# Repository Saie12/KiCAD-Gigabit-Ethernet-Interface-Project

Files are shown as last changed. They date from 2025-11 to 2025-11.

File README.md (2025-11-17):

# 🚀 High-Speed Gigabit Ethernet Interface

Welcome! This repository contains the complete hardware design files for a custom-built, 6-layer Gigabit Ethernet interface board.

The design is centered around the powerful **STM32F746NGH6** (an ARM Cortex-M7 MCU) and the **DP83867IR** Gigabit PHY. The entire layout was planned to meet strict high-speed design rules, featuring a robust multi-rail power supply and controlled impedance routing for 1Gbps performance.

## 🛠️ Key Features & Components

* **Brain (MCU):** `STM32F746NGH6` (ARM Cortex-M7)
* **Translator (PHY):** `DP83867IRPAPT` (10/100/1000 Mbps Gigabit PHY)
* **Data Interface:** `RGMII`
* **Port (Connector):** `ARJM11D7-502-AB-EW2` (A shielded Gigabit MagJack with integrated LEDs)
* **Power Supply:** 5V USB-C input, feeding a "power tree" of four independent LDOs for ultra-clean `+3.3V`, `+2.5V`, `+1.8V`, and `+1.1V` rails.
* **PCB:** Custom 6-layer, 80x50mm board with controlled impedance routing.
* **Debug:** Standard 10-pin ARM SWD (Serial Wire Debug) header.

## ✅ Hardware Project Status: Complete!

This repository covers the complete hardware design and manufacturing file generation. All phases of the hardware build are finished.

* ✅ **Phase 1: Component Selection**
    * *Selected and verified the core MCU, PHY, MagJack, and all power components for Gigabit-speed requirements.*
* ✅ **Phase 2: Schematic Design**
    * *Created the full electronic blueprint, connecting all components and defining all power and signal nets.*
* ✅ **Phase 3: Pre-Layout Checks**
    * *Ran a full Electrical Rules Check (ERC) and assigned all physical component footprints.*
* ✅ **Phase 4: PCB Layout**
    * *Designed the 6-layer stackup, floorplanned all components, poured all ground and power planes, and hand-routed all 17 critical high-speed differential and RGMII traces.*
* ✅ **Phase 5: Manufacturing File Generation**
    * *Generated the final Gerber and Drill files (`.zip`) required for fabrication.*

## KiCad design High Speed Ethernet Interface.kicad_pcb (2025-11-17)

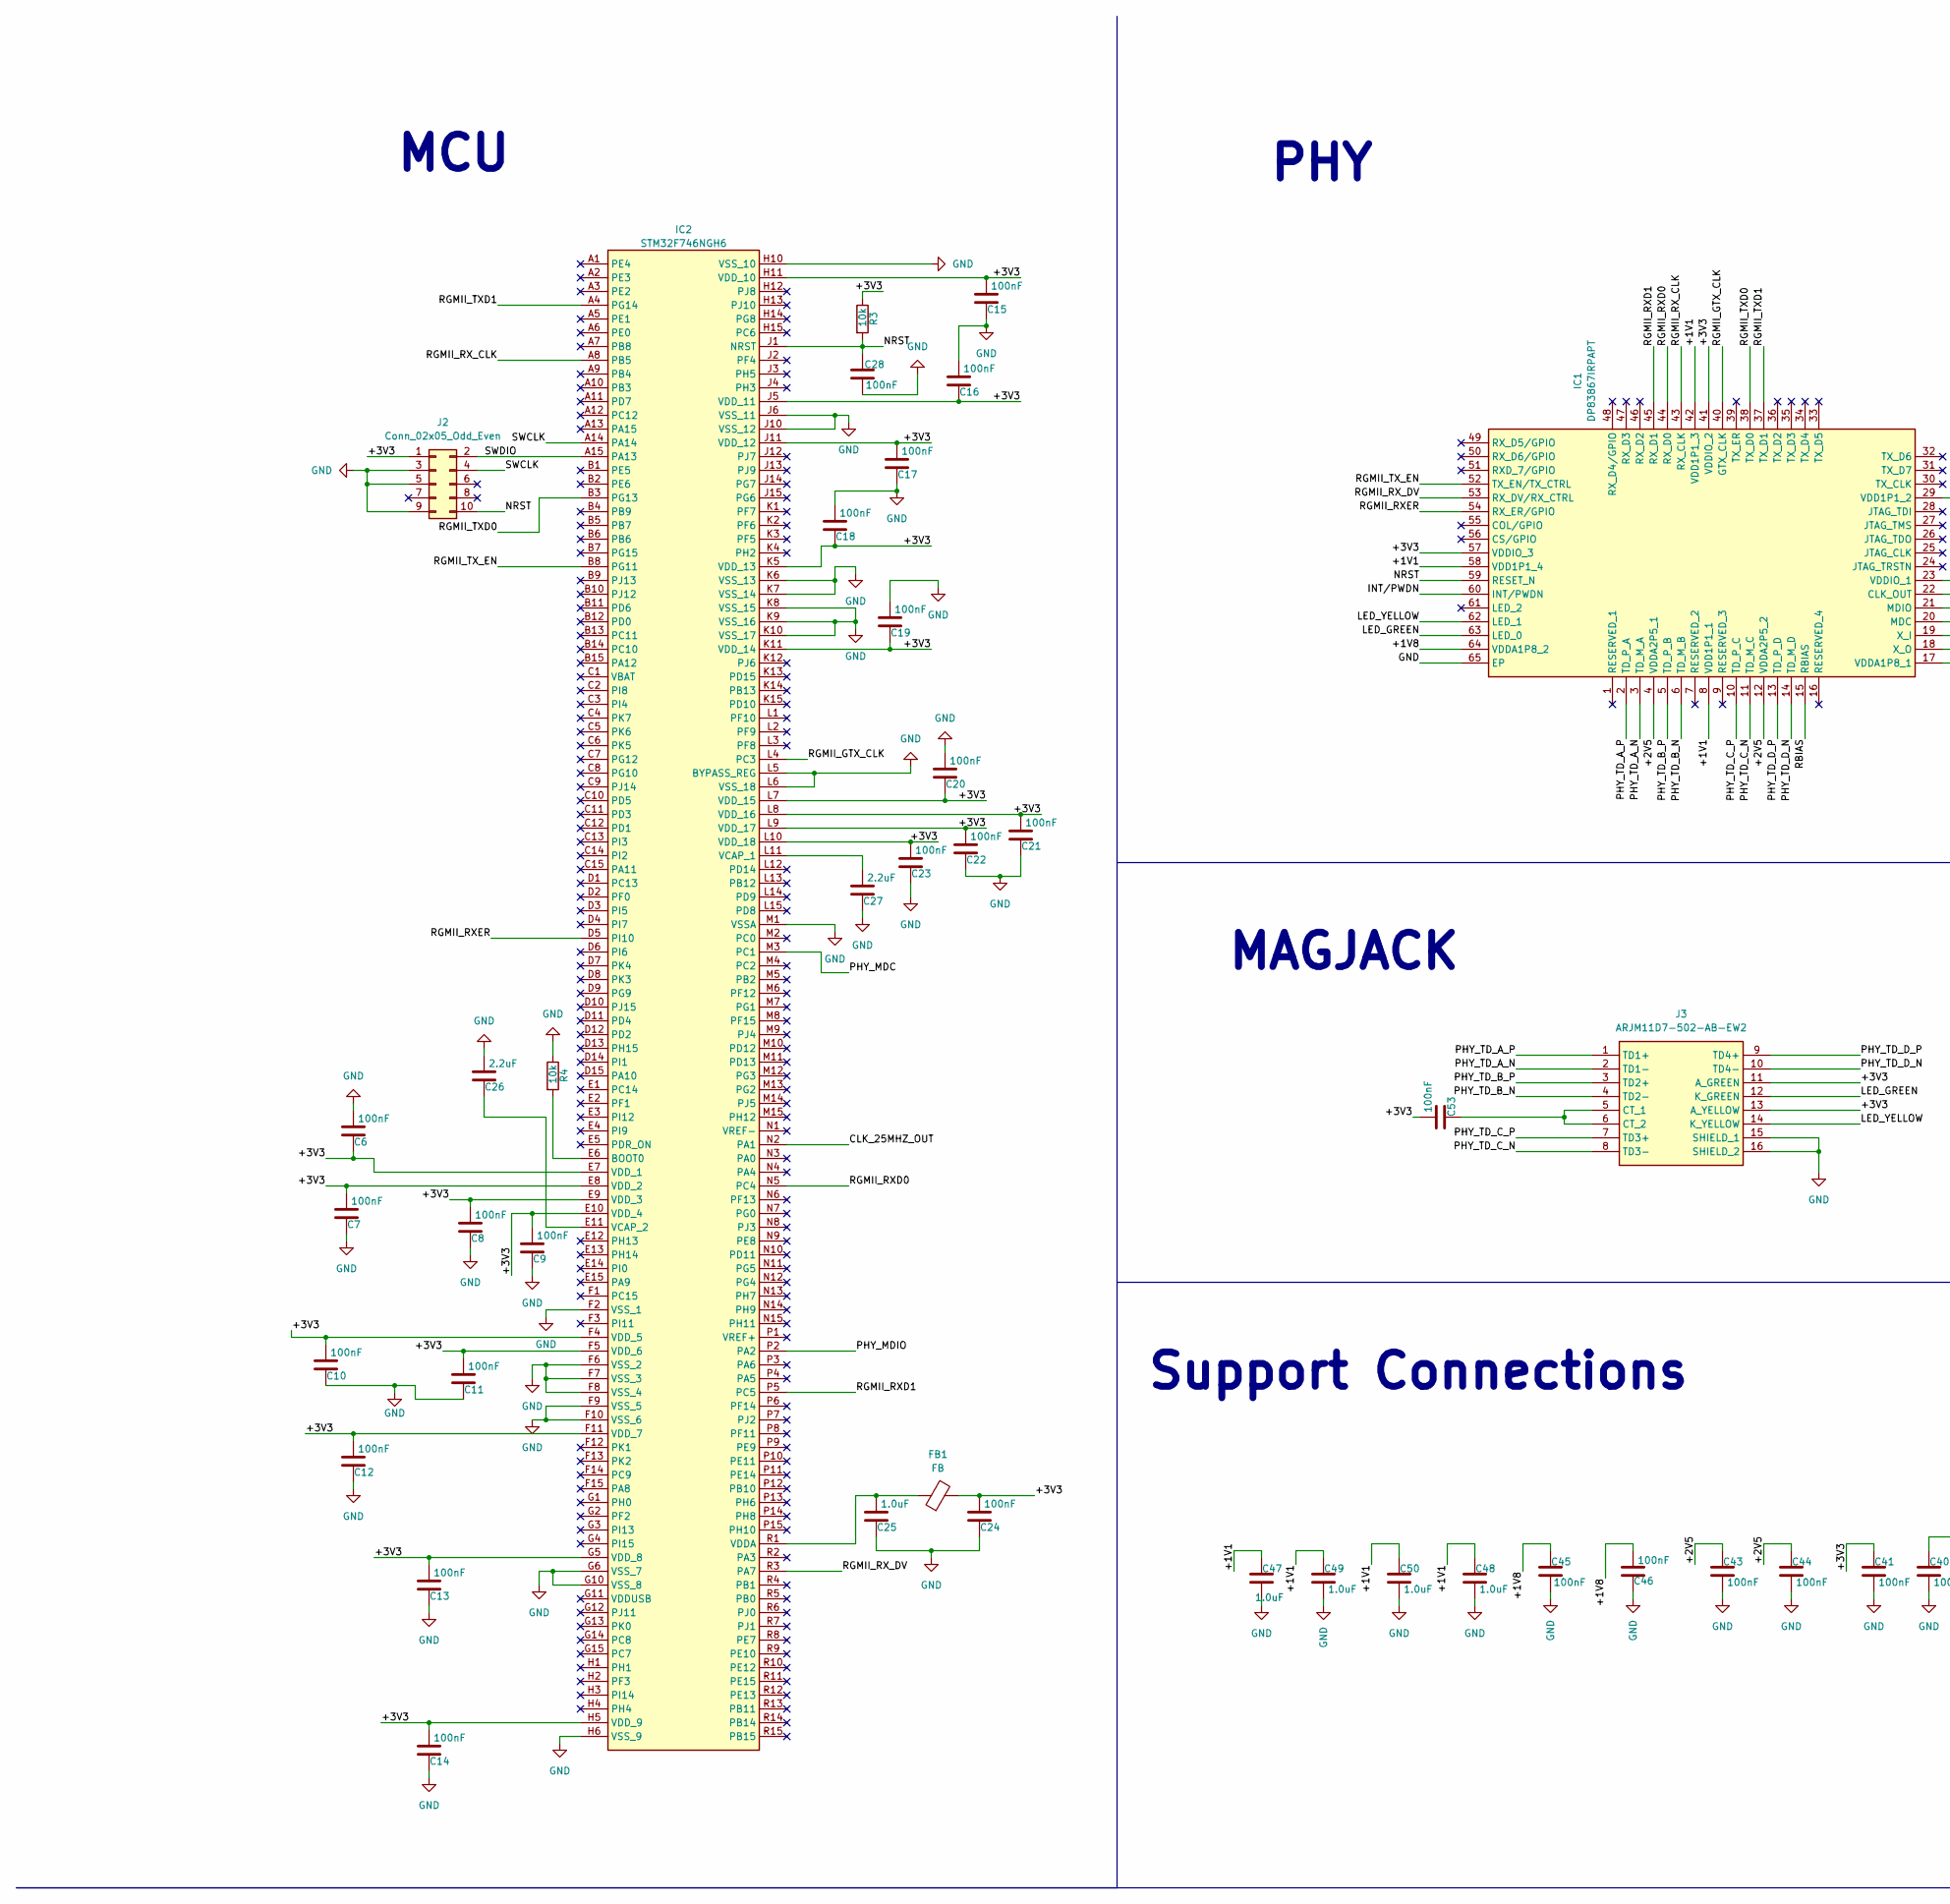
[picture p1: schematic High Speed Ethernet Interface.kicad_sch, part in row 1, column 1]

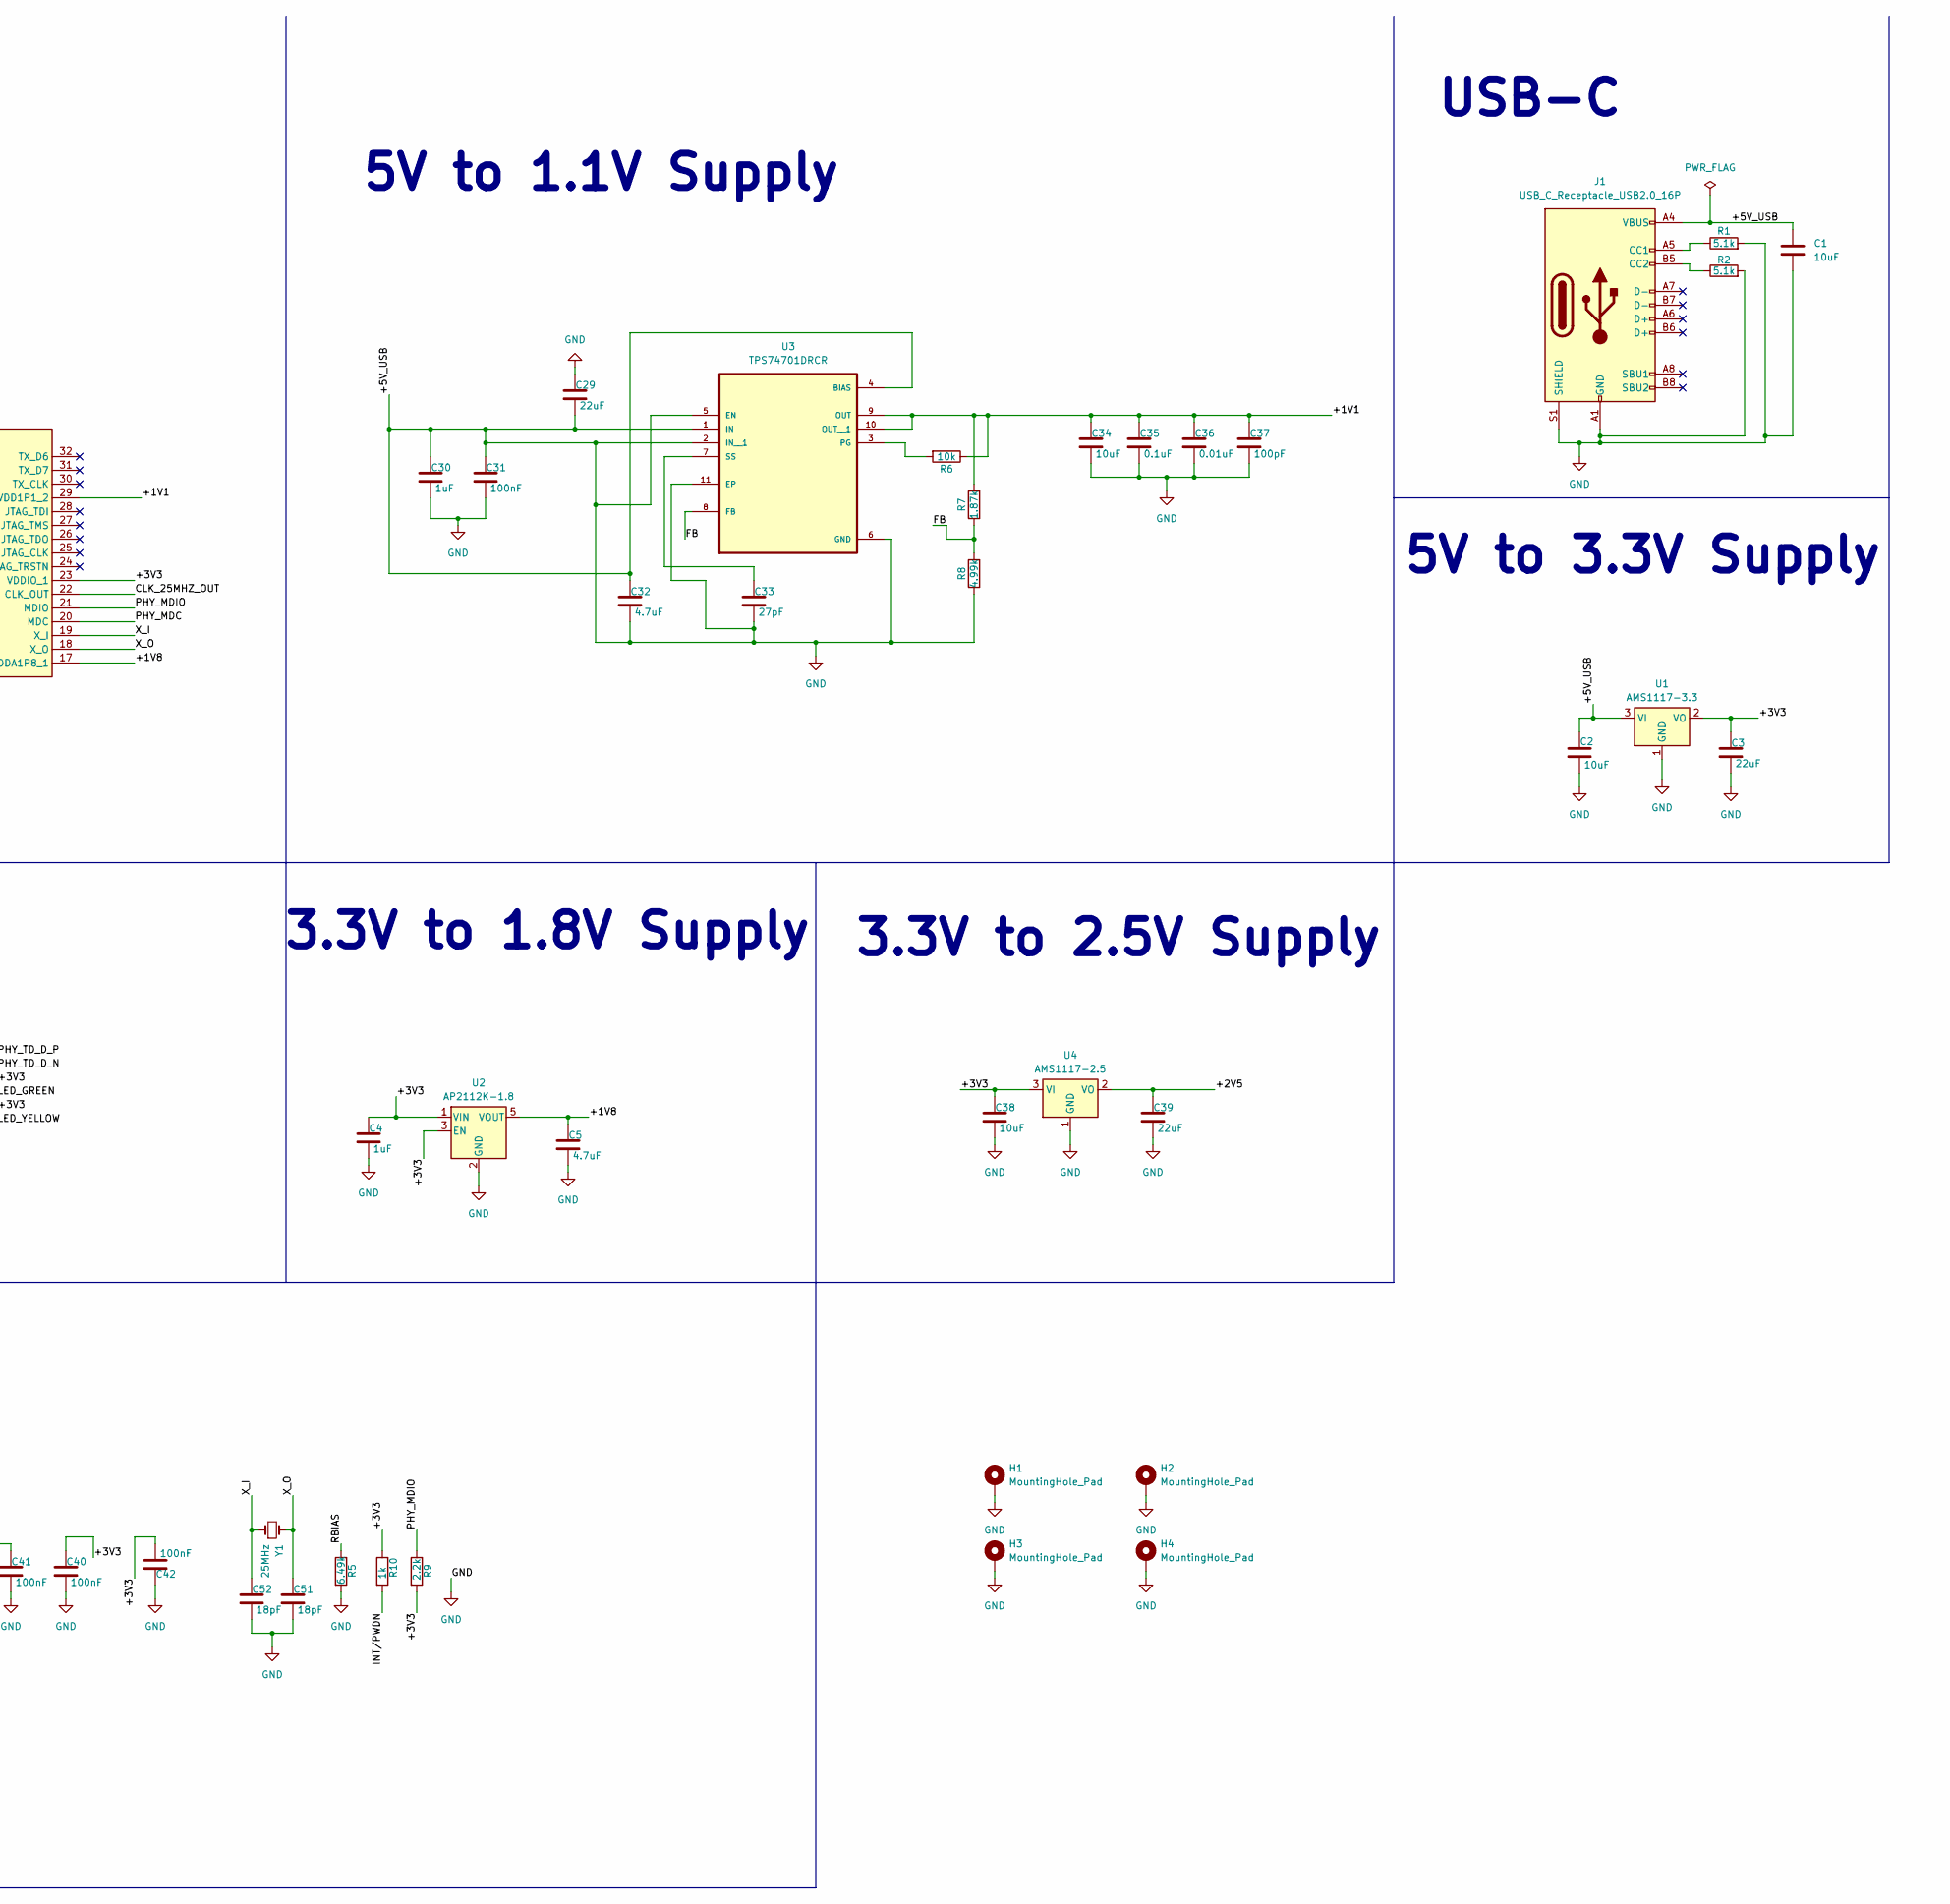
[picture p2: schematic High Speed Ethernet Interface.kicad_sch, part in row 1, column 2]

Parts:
C1, C2, C34, C38: 10uF; C_1206_3216Metric
C3, C29, C39: 22uF; C_1206_3216Metric
C4, C30: 1uF; C_0805_2012Metric
C5, C32: 4.7uF; C_1206_3216Metric
C6, C7, C8, C9, C10, C11, C12, C13, C14, C15, C16, C17, C18, C19, C20, C21, C22, C23, C24, C28, C31, C40, C41, C42, C43, C44, C45, C46, C53: 100nF; C_0805_2012Metric
C25, C47, C48, C49, C50: 1.0uF; C_0805_2012Metric
C26, C27: 2.2uF; C_1206_3216Metric
C33: 27pF; C_0805_2012Metric
C35: 0.1uF; C_0805_2012Metric
C36: 0.01uF; C_0805_2012Metric
C37: 100pF; C_0805_2012Metric
C51, C52: 18pF; C_0805_2012Metric
FB1: FB; L_0805_2012Metric
H1, H2, H3, H4: MountingHole_Pad; MountingHole_3.2mm_M3_Pad
IC1: DP83867IRPAPT; Manufacturer_Part_Number DP83867IRPAPT; Mouser Part Number 595-DP83867IRPAPT
IC2: STM32F746NGH6; Manufacturer_Part_Number STM32F746NGH6; Mouser Part Number 511-STM32F746NGH6
J1: USB_C_Receptacle_USB2.0_16P; USB_C_Receptacle_HRO_TYPE-C-31-M-12
J2: Conn_02x05_Odd_Even; PinHeader_2x05_P1.27mm_Vertical
J3: ARJM11D7-502-AB-EW2; ARJM11D7502ABEW2; Manufacturer_Part_Number ARJM11D7-502-AB-EW2; Mouser Part Number 815-RJM11D7502ABEW2
R1, R2: 5.1k; R_0805_2012Metric
R3, R4, R6: 10k; R_0805_2012Metric
R5: 6.49k; R_0805_2012Metric
R7: 1.87k; R_0805_2012Metric
R8: 4.99k; R_0805_2012Metric
R9: 2.2k; R_0805_2012Metric
R10: 1k; R_0805_2012Metric
U1: AMS1117-3.3; SOT-223-3_TabPin2
U2: AP2112K-1.8; SOT-23-5
U3: TPS74701DRCR; VREG_V62_16624-01YE
U4: AMS1117-2.5; SOT-223-3_TabPin2
Y1: 25MHz; Crystal_SMD_3225-4Pin_3.2x2.5mm

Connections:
/+1V1: C34.1, C35.1, C36.1, C37.1, C47.1, C48.1, C49.1, C50.1, IC1.8 (VDD1P1_1), IC1.29 (VDD1P1_2), IC1.42 (VDD1P1_3), IC1.58 (VDD1P1_4), R6.1, R7.2, U3.9 (OUT), U3.10 (OUT__1)
/+1V8: C5.1, C45.1, C46.2, IC1.17 (VDDA1P8_1), IC1.64 (VDDA1P8_2), U2.5 (VOUT)
/+2V5: C39.1, C43.1, C44.1, IC1.4 (VDDA2P5_1), IC1.12 (VDDA2P5_2), U4.2 (VO)
/+3V3: C3.1, C4.1, C6.1, C7.2, C8.2, C9.2, C10.2, C11.2, C12.2, C13.2, C14.2, C15.2, C16.1, C17.2, C18.1, C19.1, C20.1, C21.2, C22.2, C23.2, C24.2, C38.1, C40.1, C41.1, C42.2, C53.2, FB1.2, IC1.23 (VDDIO_1), IC1.41 (VDDIO_2), IC1.57 (VDDIO_3), IC2.E7 (VDD_1), IC2.E8 (VDD_2), IC2.E9 (VDD_3), IC2.E10 (VDD_4), IC2.F4 (VDD_5), IC2.F5 (VDD_6), IC2.F11 (VDD_7), IC2.G5 (VDD_8), IC2.H5 (VDD_9), IC2.H11 (VDD_10), IC2.J5 (VDD_11), IC2.J11 (VDD_12), IC2.K5 (VDD_13), IC2.K11 (VDD_14), IC2.L7 (VDD_15), IC2.L8 (VDD_16), IC2.L9 (VDD_17), IC2.L10 (VDD_18), J2.1, J3.11 (A_GREEN), J3.13 (A_YELLOW), R3.1, R9.2, R10.1, U1.2 (VO), U2.1 (VIN), U2.3 (EN), U4.3 (VI)
/CLK_25MHZ_OUT: IC1.22 (CLK_OUT), IC2.N2 (PA1)
/FB: R7.1, R8.2, U3.8 (FB)
/INT/PWDN: IC1.60 (INT/PWDN), R10.2
/LED_GREEN: IC1.63 (LED_0), J3.12 (K_GREEN)
/LED_YELLOW: IC1.62 (LED_1), J3.14 (K_YELLOW)
/NRST: C28.1, IC1.59 (RESET_N), IC2.J1 (NRST), J2.10, R3.2
/PHY_MDC: IC1.20 (MDC), IC2.M3 (PC1)
/PHY_MDIO: IC1.21 (MDIO), IC2.P2 (PA2), R9.1
/PHY_TD_A_N: IC1.3 (TD_M_A), J3.2 (TD1-)
/PHY_TD_A_P: IC1.2 (TD_P_A), J3.1 (TD1+)
/PHY_TD_B_N: IC1.6 (TD_M_B), J3.4 (TD2-)
/PHY_TD_B_P: IC1.5 (TD_P_B), J3.3 (TD2+)
/PHY_TD_C_N: IC1.11 (TD_M_C), J3.8 (TD3-)
/PHY_TD_C_P: IC1.10 (TD_P_C), J3.7 (TD3+)
/PHY_TD_D_N: IC1.14 (TD_M_D), J3.10 (TD4-)
/PHY_TD_D_P: IC1.13 (TD_P_D), J3.9 (TD4+)
/RBIAS: IC1.15 (RBIAS), R5.1
/RGMII_GTX_CLK: IC1.40 (GTX_CLK), IC2.L4 (PC3)
/RGMII_RXD0: IC1.44 (RX_D0), IC2.N5 (PC4)
/RGMII_RXD1: IC1.45 (RX_D1), IC2.P5 (PC5)
/RGMII_RXER: IC1.54 (RX_ER/GPIO), IC2.D5 (PI10)
/RGMII_RX_CLK: IC1.43 (RX_CLK), IC2.A8 (PB5)
/RGMII_RX_DV: IC1.53 (RX_DV/RX_CTRL), IC2.R3 (PA7)
/RGMII_TXD0: IC1.38 (TX_D0), IC2.B3 (PG13)
/RGMII_TXD1: IC1.37 (TX_D1), IC2.A4 (PG14)
/RGMII_TX_EN: IC1.52 (TX_EN/TX_CTRL), IC2.B8 (PG11)
/SWCLK: IC2.A14, J2.4
/SWDIO: IC2.A15 (PA13), J2.2
/X_I: C52.1, IC1.19 (X_I), Y1.1
/X_O: C51.1, IC1.18 (X_O), Y1.2
GND: C1.1, C1.2, C2.1, C2.2, C3.2, C4.2, C5.2, C6.2, C7.1, C8.1, C9.1, C10.1, C11.1, C12.1, C13.1, C14.1, C15.1, C16.2, C17.1, C18.2, C19.2, C20.2, C21.1, C22.1, C23.1, C24.1, C25.1, C26.2, C27.1, C28.2, C29.1, C29.2, C30.1, C30.2, C31.1, C31.2, C32.1, C32.2, C33.2, C34.2, C35.2, C36.2, C37.2, C38.2, C39.2, C40.2, C41.2, C42.1, C43.2, C44.2, C45.2, C46.1, C47.2, C48.2, C49.2, C50.2, C51.2, C52.2, H1.1, H2.1, H3.1, H4.1, IC1.65 (EP), IC2.F2 (VSS_1), IC2.F6 (VSS_2), IC2.F7 (VSS_3), IC2.F8 (VSS_4), IC2.F9 (VSS_5), IC2.F10 (VSS_6), IC2.G6 (VSS_7), IC2.G10 (VSS_8), IC2.H6 (VSS_9), IC2.H10 (VSS_10), IC2.J6 (VSS_11), IC2.J10 (VSS_12), IC2.K6 (VSS_13), IC2.K7 (VSS_14), IC2.K8 (VSS_15), IC2.K9 (VSS_16), IC2.K10 (VSS_17), IC2.L5 (BYPASS_REG), IC2.L6 (VSS_18), IC2.M1 (VSSA), J1.A1 (GND), J1.A4 (VBUS), J1.A9 (VBUS), J1.A12 (GND), J1.B1 (GND), J1.B4 (VBUS), J1.B9 (VBUS), J1.B12 (GND), J1.S1 (SHIELD), J2.3, J2.5, J2.9, J3.15 (SHIELD_1), J3.16 (SHIELD_2), R1.2, R2.2, R4.1, R5.2, R8.1, U1.1 (GND), U1.3 (VI), U2.2 (GND), U3.1 (IN), U3.2 (IN__1), U3.4 (BIAS), U3.5 (EN), U3.6 (GND), U3.11 (EP), U3.12, U3.13, U3.14, U3.15, U4.1 (GND)
unnamed: IC2.E6 (BOOT0), R4.2
unnamed: C27.2, IC2.L11 (VCAP_1)
unnamed: C26.1, IC2.E11 (VCAP_2)
unnamed: C25.2, FB1.1, IC2.R1 (VDDA)
unnamed: J1.A5 (CC1), R1.1
unnamed: J1.B5 (CC2), R2.1
unnamed: C53.1, J3.5 (CT_1), J3.6 (CT_2)
unnamed: R6.2, U3.3 (PG)
unnamed: C33.1, U3.7 (SS)

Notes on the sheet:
Support Connections
5V to 3.3V Supply
PHY
USB-C
5V to 1.1V Supply
MAGJACK
MCU
3.3V to 1.8V Supply
3.3V to 2.5V Supply

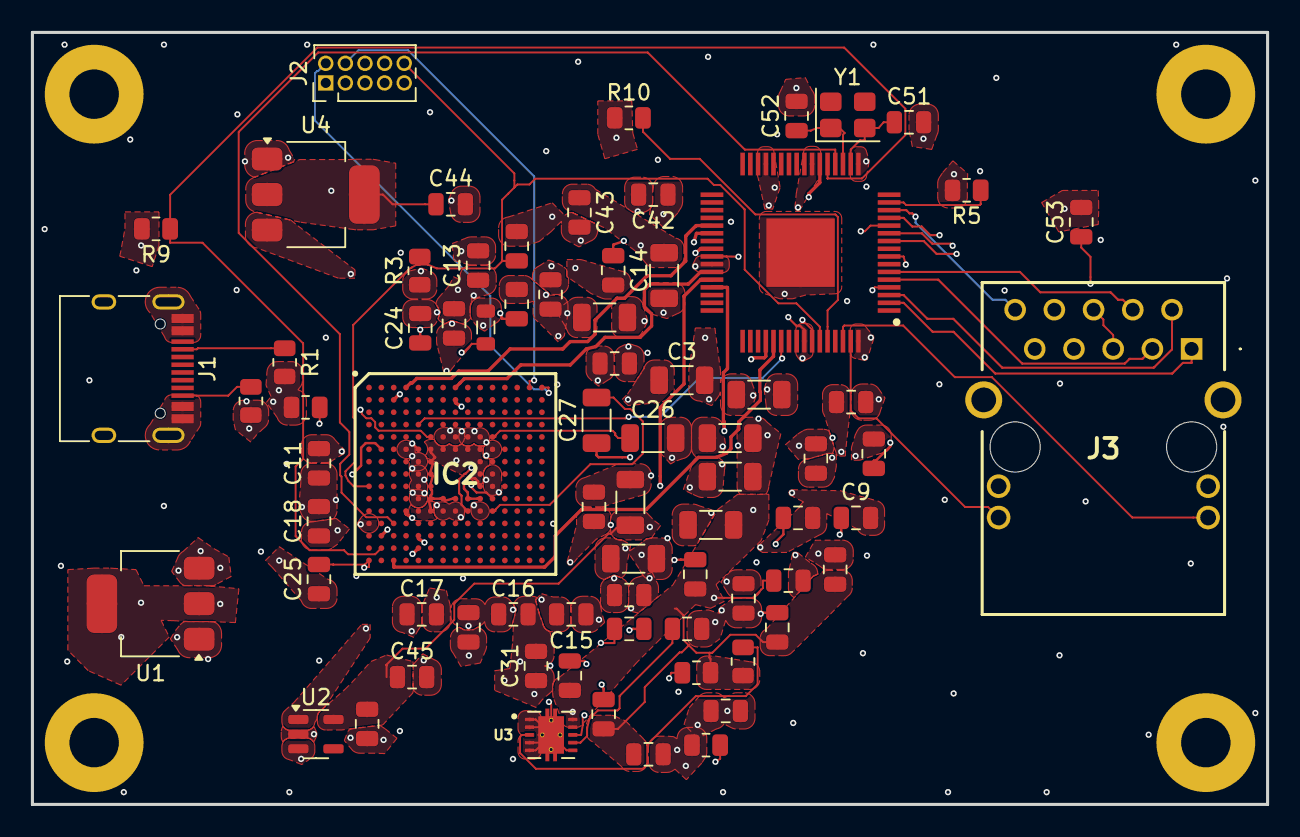
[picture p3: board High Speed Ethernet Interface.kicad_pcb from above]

Board: 6 copper layers, 80.0 x 50.0 mm, 78 parts (0 on the bottom side), 44 nets.

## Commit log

2025-11-17 Initial commit of Gigabit Ethernet project
    [High Speed Ethernet Interface-B_Paste.gbp, High Speed Ethernet Interface-Board Layer Stack Bottom Overlay.gbo, High Speed Ethernet Interface-Board Layer Stack 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]
2025-11-17 Add README for Gigabit Ethernet Interface project
    This README provides an overview of the hardware design files for a custom-built Gigabit Ethernet interface board, detailing its components, features, and project status.
